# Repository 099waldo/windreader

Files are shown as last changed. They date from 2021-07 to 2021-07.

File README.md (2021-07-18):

# WindReader

WindReader is a Raspberry Pi hat for reading sensor data from the NRG #40 Anemometer and the NRG 200P direction vane from NRG Systems. 

It uses the popular LM741 op amp as well as the MCP3008 analog to digital converter in order to send the analog sensor readings 
to the Raspberry Pi.

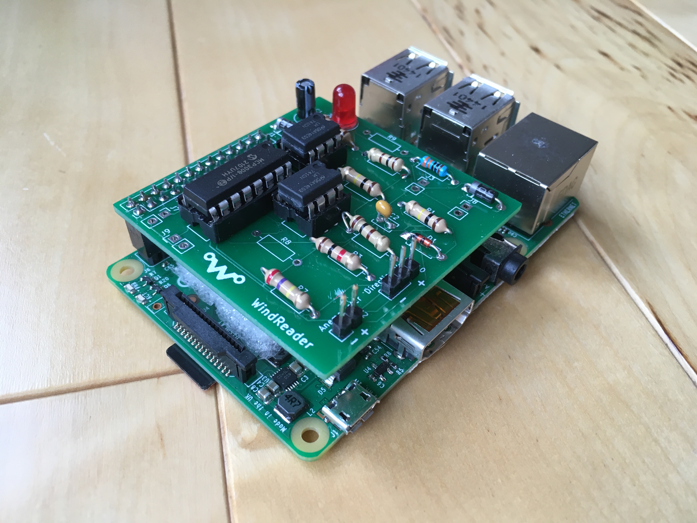
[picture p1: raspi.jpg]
Raspberry Pi and WindReader


The project started when I scored some free wind sensors from an old weather station. It seemed like the perfect opprotunity to try 
my hand at pcb design! 

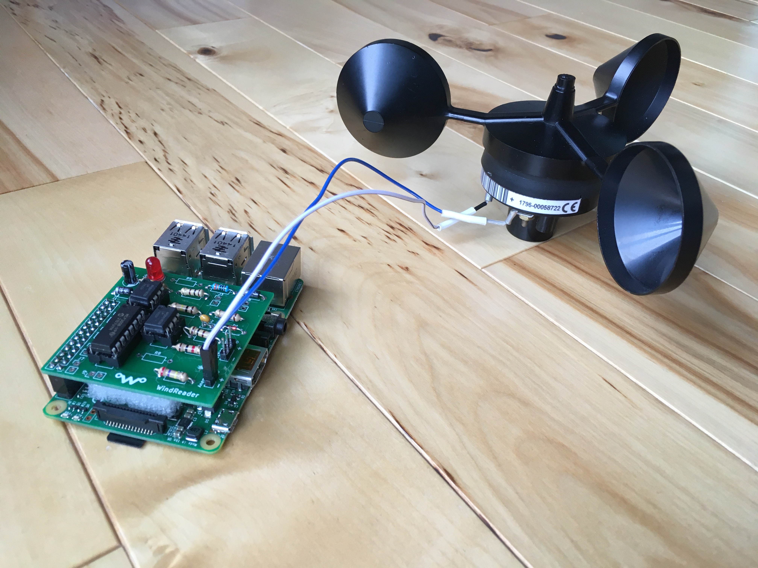
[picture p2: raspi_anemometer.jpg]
WindReader and Anemometer


Unfortunatly, upon further inspection, the only direction vane I got didn't work but in theory the circuit should work fine. 
If I am able to get my hands on a working one I will confirm this.

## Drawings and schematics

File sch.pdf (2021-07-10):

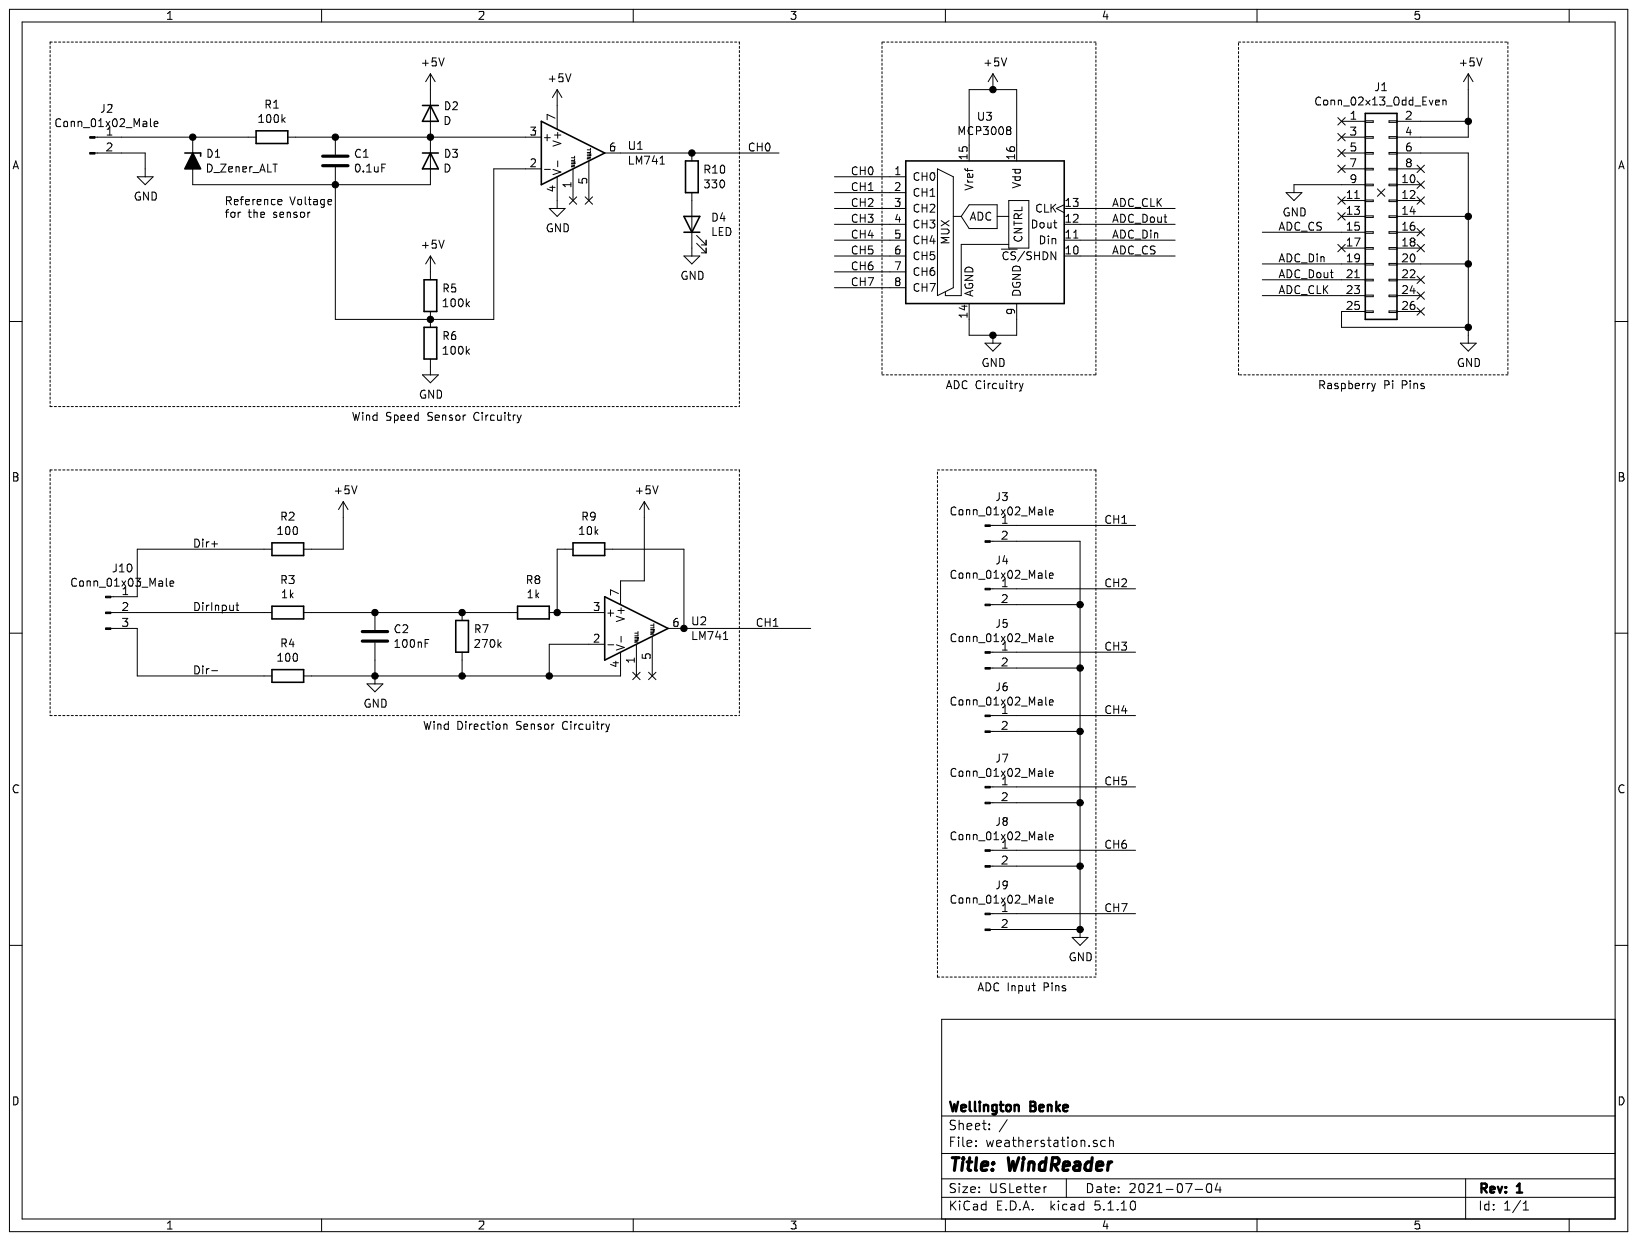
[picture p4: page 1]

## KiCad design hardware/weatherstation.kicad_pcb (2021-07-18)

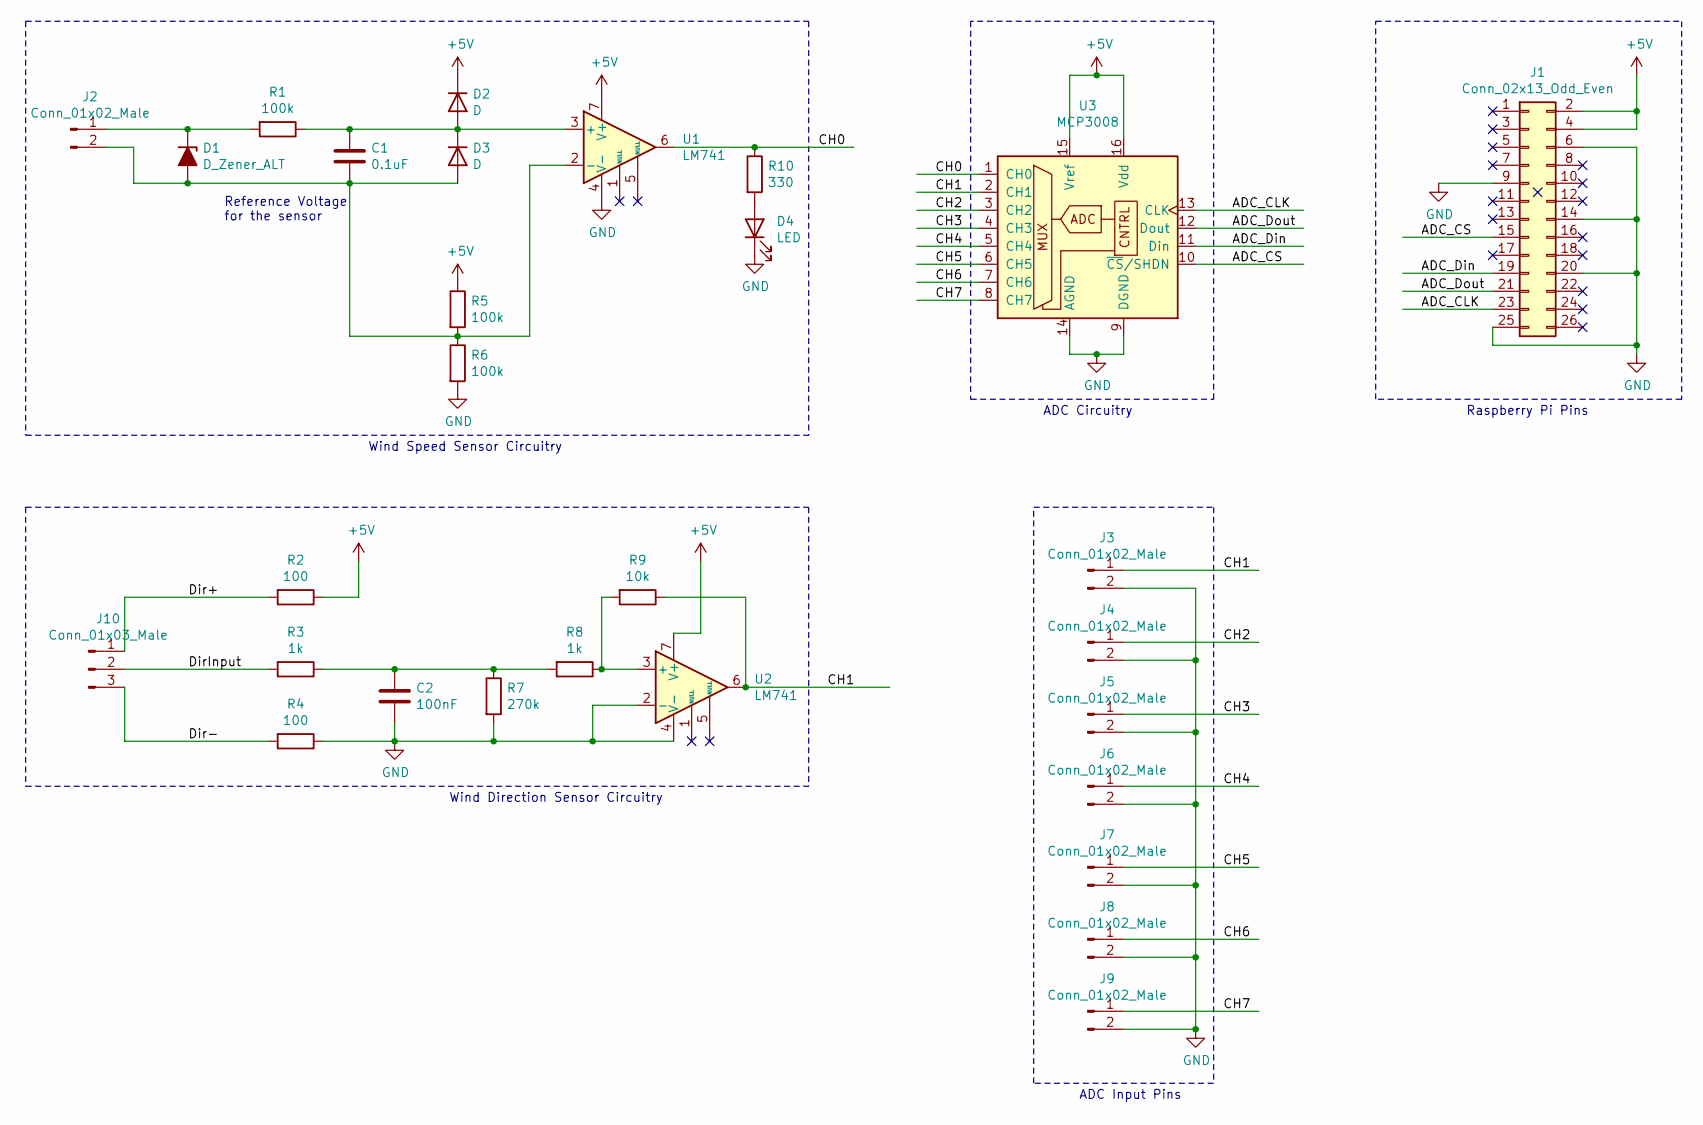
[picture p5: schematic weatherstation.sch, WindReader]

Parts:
C1: 0.1uF; CP_Radial_D5.0mm_P2.50mm
C2: 100nF; C_Rect_L4.0mm_W2.5mm_P2.50mm
D1: D_Zener_ALT; D_A-405_P7.62mm_Horizontal
D2, D3: D; D_A-405_P7.62mm_Horizontal
D4: LED; LED_D5.0mm
J1: Conn_02x13_Odd_Even; PinHeader_2x13_P2.54mm_Vertical
J2, J3, J4, J5, J6, J7, J8, J9: Conn_01x02_Male; PinHeader_1x02_P2.54mm_Vertical
J10: Conn_01x03_Male; PinHeader_1x03_P2.54mm_Vertical
R1, R5, R6: 100k; R_Axial_DIN0207_L6.3mm_D2.5mm_P10.16mm_Horizontal
R2, R4: 100; R_Axial_DIN0207_L6.3mm_D2.5mm_P10.16mm_Horizontal
R3, R8: 1k; R_Axial_DIN0207_L6.3mm_D2.5mm_P10.16mm_Horizontal
R7: 270k; R_Axial_DIN0207_L6.3mm_D2.5mm_P10.16mm_Horizontal
R9: 10k; R_Axial_DIN0207_L6.3mm_D2.5mm_P10.16mm_Horizontal
R10: 330; R_Axial_DIN0207_L6.3mm_D2.5mm_P10.16mm_Horizontal
U1, U2: LM741; DIP-8_W7.62mm
U3: MCP3008; DIP-16_W7.62mm

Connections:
+5V: D2.1 (K), J1.2, J1.4, R2.1, R5.1, U1.7 (V+), U2.7 (V+), U3.15 (Vref), U3.16 (Vdd)
/ADC_CLK: J1.23, U3.13 (CLK)
/ADC_CS: J1.15, U3.10 (~CS~/SHDN)
/ADC_Din: J1.19, U3.11 (Din)
/ADC_Dout: J1.21, U3.12 (Dout)
/CH0: R10.1, U1.6, U3.1 (CH0)
/CH1: J3.1, R9.1, U2.6, U3.2 (CH1)
/CH2: J4.1, U3.3 (CH2)
/CH3: J5.1, U3.4 (CH3)
/CH4: J6.1, U3.5 (CH4)
/CH5: J7.1, U3.6 (CH5)
/CH6: J8.1, U3.7 (CH6)
/CH7: J9.1, U3.8 (CH7)
/Dir+: J10.1, R2.2
/Dir-: J10.3, R4.2
/DirInput: J10.2, R3.2
GND: C2.2, D4.1 (K), J1.6, J1.9, J1.14, J1.20, J1.25, J3.2, J4.2, J5.2, J6.2, J7.2, J8.2, J9.2, R4.1, R6.2, R7.2, U1.4 (V-), U2.2 (-), U2.4 (V-), U3.9 (DGND), U3.14 (AGND)
unnamed: C1.1, D2.2 (A), D3.1 (K), R1.1, U1.3 (+)
unnamed: C1.2, D1.2 (A), D3.2 (A), J2.2, R5.2, R6.1, U1.2 (-)
unnamed: C2.1, R3.1, R7.1, R8.2
unnamed: D1.1 (K), J2.1, R1.2
unnamed: D4.2 (A), R10.2
unnamed: R8.1, R9.2, U2.3 (+)

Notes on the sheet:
Reference Voltage for the sensor
Wind Speed Sensor Circuitry
Raspberry Pi Pins
ADC Circuitry
Wind Direction Sensor Circuitry
ADC Input Pins

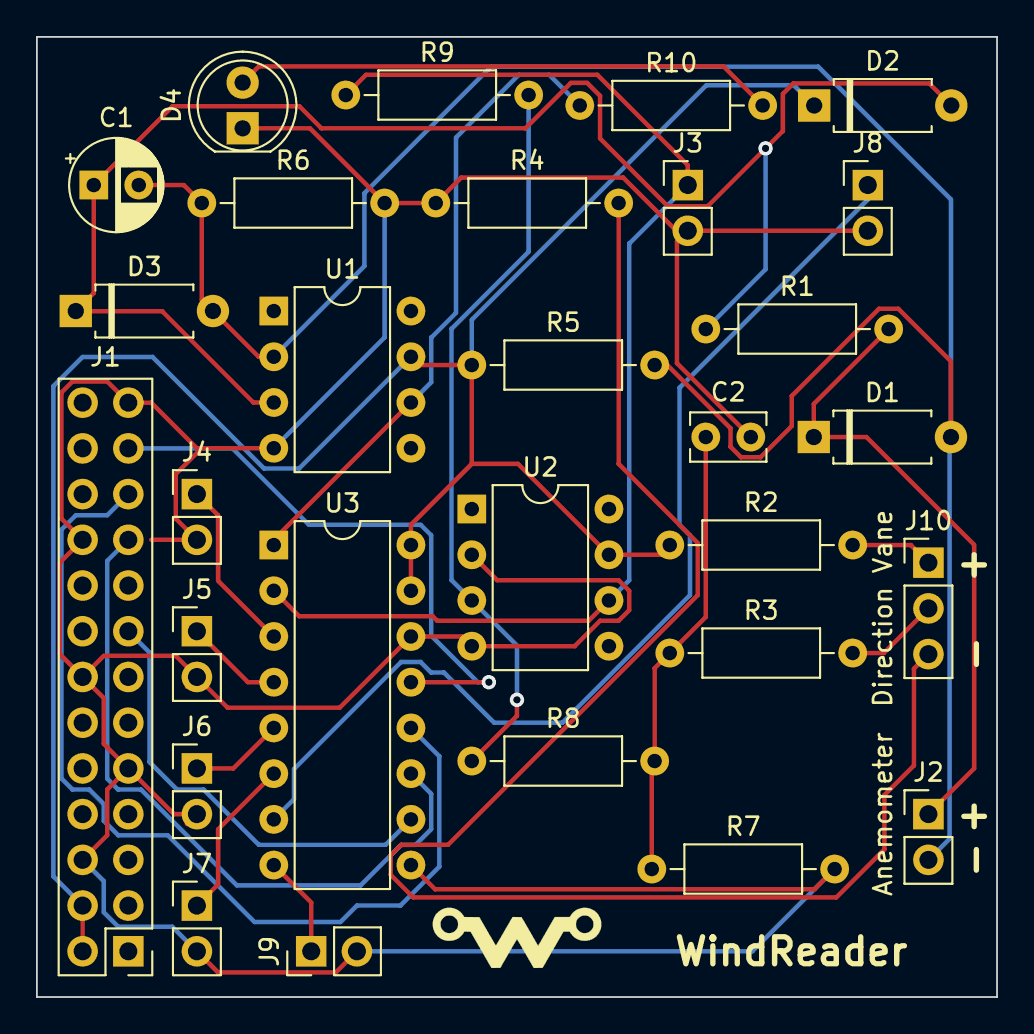
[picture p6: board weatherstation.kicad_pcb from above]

Board: 2 copper layers, 53.3 x 53.3 mm, 29 parts (0 on the bottom side), 23 nets.

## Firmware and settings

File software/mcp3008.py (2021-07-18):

#!/usr/bin/env python3

from time import sleep
import board
import busio
import digitalio
import adafruit_mcp3xxx.mcp3008 as MCP3008
from adafruit_mcp3xxx.analog_in import AnalogIn
import RPi.GPIO

SPI = busio.SPI(clock=board.SCK, MISO=board.MISO, MOSI=board.MOSI)
MCP3008_CS = digitalio.DigitalInOut(board.D22)
MCP3008_SPI = MCP3008.MCP3008(SPI, MCP3008_CS)
ADC_CH0 = AnalogIn(MCP3008_SPI, MCP3008.P0)
ADC_CH1 = AnalogIn(MCP3008_SPI, MCP3008.P1)
ADC_DIFF = AnalogIn(MCP3008_SPI, MCP3008.P1, MCP3008.P0)

currenttime=0
waittime = 1/150
lastbit = 0
hz=0

totalcounts=0
tally=0

print("Press CTRL-C to exit.")
try:
	while True:
		#print(f"ADC  CH0: {ADC_CH0.voltage:4.2f} V ({ADC_CH0.value:5d})")
		#print()
		ledon = ADC_CH0.voltage > 1.5
		if lastbit != ledon:
			hz += 1
			lastbit = ledon

		sleep(waittime)
		currenttime += 1
		if currenttime == 150:
			#ms = (0.95*hz) + 0.35
			rs = hz + 1.0

			ms = rs*0.095
			tally+=ms
			totalcounts+=1
			print(f"Speed: {ms:4.2f} m/s")
			hz=0
			currenttime = 0
except KeyboardInterrupt:
	RPi.GPIO.cleanup()
	print("\nCleaned up GPIO resources.")
	print(f"Average: {tally/totalcounts:4.2f}")

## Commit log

2021-06-08 Updated schematic
    [weatherstation.sch]
2021-06-12 Finallized schematic
    [weatherstation.sch]
2021-06-12 Added input for speed direction circuitry
    [weatherstation.sch]
2021-06-13 Added footprints to schematic and generated netlist
    [weatherstation.sch]
2021-06-13 Added resistor datasheet
2021-06-25 Added logo. Tidied up a bit
    [weatherstation.kicad_pcb]
2021-06-25 Changed name
    [weatherstation.kicad_pcb]
2021-06-25 Fixed backwards raspi header
    [weatherstation.kicad_pcb, weatherstation.sch]
2021-06-25 Moved component label back onto pcb
    [weatherstation.kicad_pcb]
2021-06-25 Added place for jlc order number
    [weatherstation.kicad_pcb]
2021-06-25 Generated Gerbers and ordered from JLC
2021-07-04 Finallized schematic exported to pdf
    [weatherstation.sch]
2021-07-10 Added forgotten component values
    [weatherstation.sch]
2021-07-10 Reorganized repo
    [weatherstation-B_Cu.gbr, weatherstation-B_Mask.gbr, weatherstation-B_Paste.gbr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]
2021-07-17 Fixed ground of anemometer going ground problem
    [weatherstation.kicad_pcb, weatherstation.sch]
2021-07-18 Callibrated sensor
